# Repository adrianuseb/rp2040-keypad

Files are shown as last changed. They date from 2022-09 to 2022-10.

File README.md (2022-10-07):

# RP2040-keypad

## Table of Contents
* [General Info](#general-information)
* [Design](#design)
* [Ordering](#ordering)
* [Flashing Firmware](#flashing-firmware)
* [Case](#case)
* [Assembly](#assembly)

## General Information

This project was made as a learning experience on how to design a MCU-based PCB with minimum components.
It is a 2-key Keypad based on Raspberry RP2040 MCU. It doesn't have any button to enter bootmode, and no LED indicator. Simplicity was the main target.

## Design

This board was designed with KiCad. It is a 4 layer board with signal on the outer layer and power on the inner layer. It has serial wire pin-hole to debugging
and a USB-C header for connection to the host and power. The switches used for the key are mechanical switches and they are connected to GPIO6 and GPIO7. The other end
of the switch connected directly to ground. For programming the BOOT jumper pad must be shorted before connecting the USB.

## Ordering

Ordering and assembly can be done easily at JLCPCB. [Manufacturing_JLCPCB](./Manufacturing_JLCPCB) provide all the necessary files like Gerber, BOM, and components
placement for ordering the board.

## Flashing firmware

Flashing firmware with RP2040 IC is a very simple task. Just short the BOOT jumper while connecting the USB to PC. The board should appear as a mass storage device
on the host PC. Then just copy the [.uf2 file](./rp2040-keypad-1000hz.uf2) there and the board should reset itself. The firmware is written with z and x as the key.

## Case

There is also a simple [case](./case.obj) for 3D printing. The following components are also required for the case:
  - 4 M2 14mm
  - 4 M2 hex nuts

## Assembly

1. Place both of the switch from the top case. It should hold the switches well
2. Align the PCB with the switch. Now should be the right time to solder the switches to the PCB
3. Insert all the hex nuts to the bottom case
4. Place the bottom case aligned with the top case and press until the PCB sits on the bottom case
5. Screw all the M2 screws to secure the case

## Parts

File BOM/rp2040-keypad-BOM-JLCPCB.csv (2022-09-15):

Comment | Designator | Footprint | LCSC
22u | C1,C2 | Capacitor_SMD:C_0603_1608Metric | C59461
22p | C16,C17 | Capacitor_SMD:C_0402_1005Metric | C1555
100n | C3,C4,C6,C7,C8,C9,C10,C11,C12,C13,C15 | Capacitor_SMD:C_0402_1005Metric | C1525
1u | C5,C14 | Capacitor_SMD:C_0402_1005Metric | C52923
USB_C_Receptacle_USB2.0 | J1 | Connector_USB:USB_C_Receptacle_HRO_TYPE-C-31-M-12 | C165948
5k1 | R1,R2 | Resistor_SMD:R_0402_1005Metric | C25905
27R4 | R3,R4 | Resistor_SMD:R_0402_1005Metric | C31439
1k | R5,R6 | Resistor_SMD:R_0402_1005Metric | C11702
AMS1117-3.3 | U1 | Package_TO_SOT_SMD:SOT-223-3_TabPin2 | C6186
RP2040 | U2 | Package_DFN_QFN:QFN-56-1EP_7x7mm_P0.4mm_EP3.2x3.2mm | C2040
W25Q128JVS | U3 | Package_SO:SOIC-8_5.23x5.23mm_P1.27mm | C97521
12Mhz | Y1 | Crystal:Crystal_SMD_3225-4Pin_3.2x2.5mm | C9002

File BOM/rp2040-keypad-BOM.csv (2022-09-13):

Source: | C:\Users\AugmentedRobotics014\Documents\GIThub\rp2040-keypad\KiCad\rp2040-keypad.kicad_sch
Date: | 13/09/2022 17:31:18
Tool: | Eeschema (6.0.7)
Generator: | C:\Program Files\KiCad\6.0\bin\scripting\plugins/bom_csv_grouped_by_value_with_fp.py
Component Count: | 36
Ref | Qnty | Value | Cmp name | Footprint | Description | Vendor
C1, C2, | 2 | 22u | C | Capacitor_SMD:C_0603_1608Metric | Unpolarized capacitor
C3, C4, C6, C7, C8, C9, C10, C11, C12, C13, C15, | 11 | 100n | C | Capacitor_SMD:C_0402_1005Metric | Unpolarized capacitor
C5, C14, | 2 | 1u | C | Capacitor_SMD:C_0402_1005Metric | Unpolarized capacitor
C16, C17, | 2 | 22p | C | Capacitor_SMD:C_0402_1005Metric | Unpolarized capacitor
H1, H2, H3, H4, | 4 | MountingHole | MountingHole | MountingHole:MountingHole_2.2mm_M2_DIN965 | Mounting Hole without connection
J1, | 1 | USB_C_Receptacle_USB2.0 | USB_C_Receptacle_USB2.0 | Connector_USB:USB_C_Receptacle_HRO_TYPE-C-31-M-12 | USB 2.0-only Type-C Receptacle connector
J2, | 1 | Conn_01x04_Male | Conn_01x04_Male | Connector_Wire:SolderWire-0.1sqmm_1x04_P3.6mm_D0.4mm_OD1mm | Generic connector, single row, 01x04, script generated (kicad-library-utils/schlib/autogen/connector/)
JP1, | 1 | 0 | SolderJumper_2_Open | Jumper:SolderJumper-2_P1.3mm_Open_Pad1.0x1.5mm | Solder Jumper, 2-pole, open
R1, R2, | 2 | 5k1 | R | Resistor_SMD:R_0402_1005Metric | Resistor
R3, R4, | 2 | 27R4 | R | Resistor_SMD:R_0402_1005Metric | Resistor
R5, R6, | 2 | 1k | R | Resistor_SMD:R_0402_1005Metric | Resistor
SW1, SW2, | 2 | SW_Push | SW_Push | Switch_Keyboard_Cherry_MX:SW_Cherry_MX_PCB_1.00u | Push button switch, generic, two pins
U1, | 1 | AMS1117-3.3 | AMS1117-3.3 | Package_TO_SOT_SMD:SOT-223-3_TabPin2 | 1A Low Dropout regulator, positive, 3.3V fixed output, SOT-223
U2, | 1 | RP2040 | RP2040 | Package_DFN_QFN:QFN-56-1EP_7x7mm_P0.4mm_EP3.2x3.2mm | A microcontroller by Raspberry Pi
U3, | 1 | W25Q128JVS | W25Q128JVS | Package_SO:SOIC-8_5.23x5.23mm_P1.27mm | 128Mb Serial Flash Memory, Standard/Dual/Quad SPI, SOIC-8
Y1, | 1 | 12Mhz | Crystal_GND24 | Crystal:Crystal_SMD_3225-4Pin_3.2x2.5mm | Four pin crystal, GND on pins 2 and 4

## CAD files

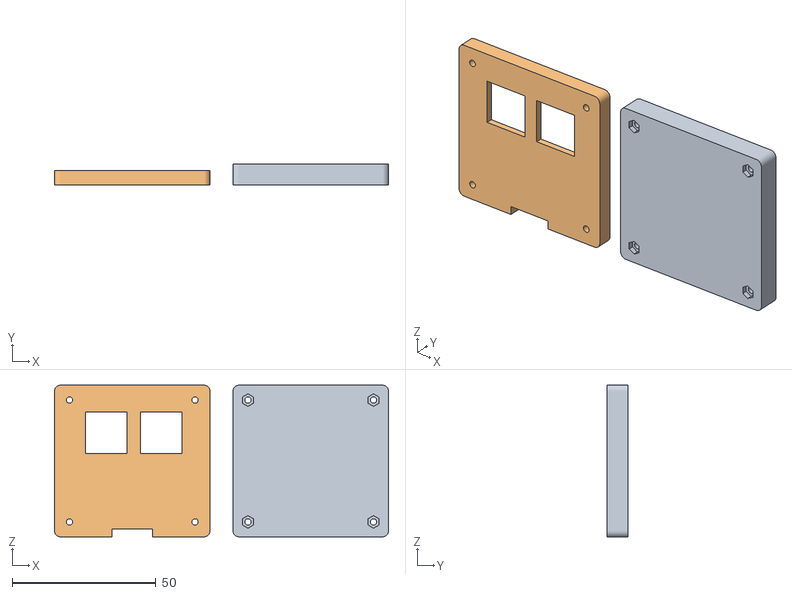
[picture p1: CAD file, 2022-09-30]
case.obj
116.2 x 7.19 x 52.8
Mesh1 Group1 Model
Mesh19 Group2 Model

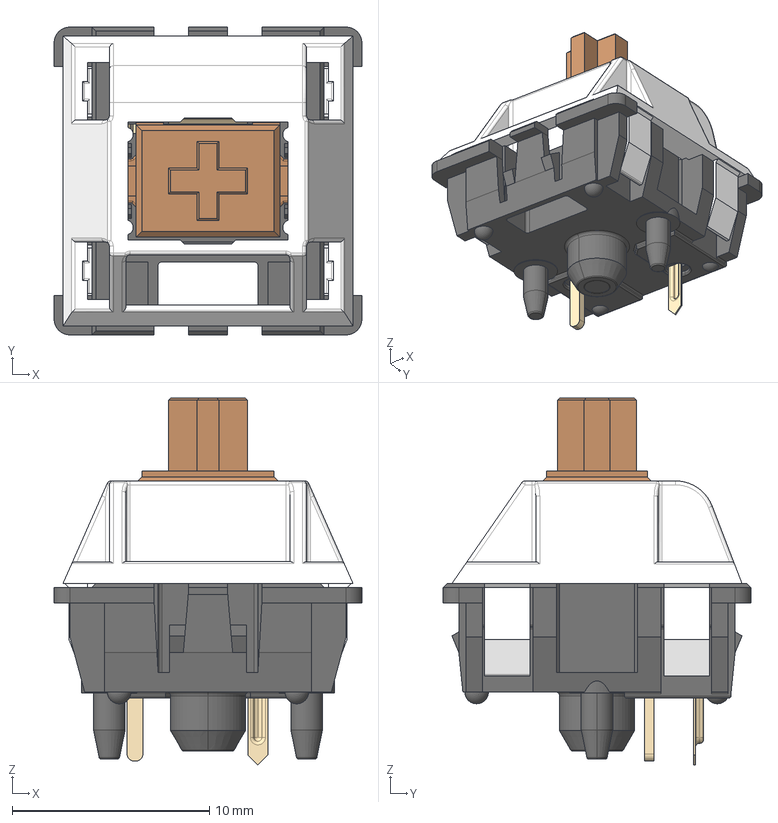
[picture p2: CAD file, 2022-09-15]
KiCad/Custom Library/3D Library/SW_Cherry_MX_PCB.stp
15.6 x 15.6 x 18.6 mm

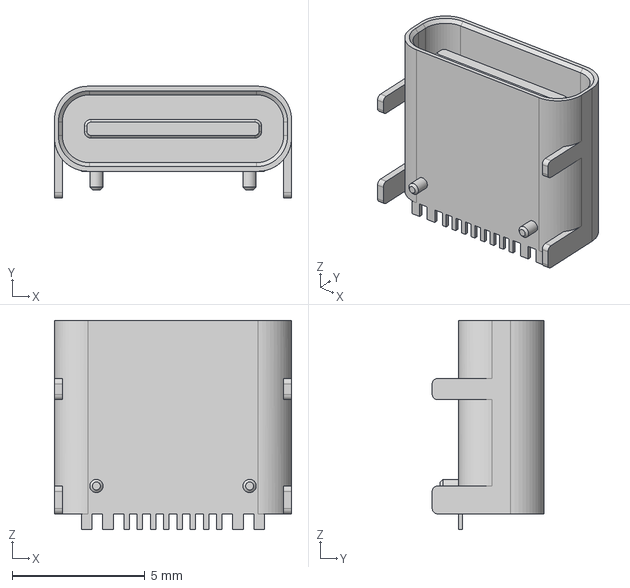
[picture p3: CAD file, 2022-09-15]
KiCad/Custom Library/3D Library/HRO TYPE-C-31-M-12.step
8.94 x 4.21 x 7.90 mm

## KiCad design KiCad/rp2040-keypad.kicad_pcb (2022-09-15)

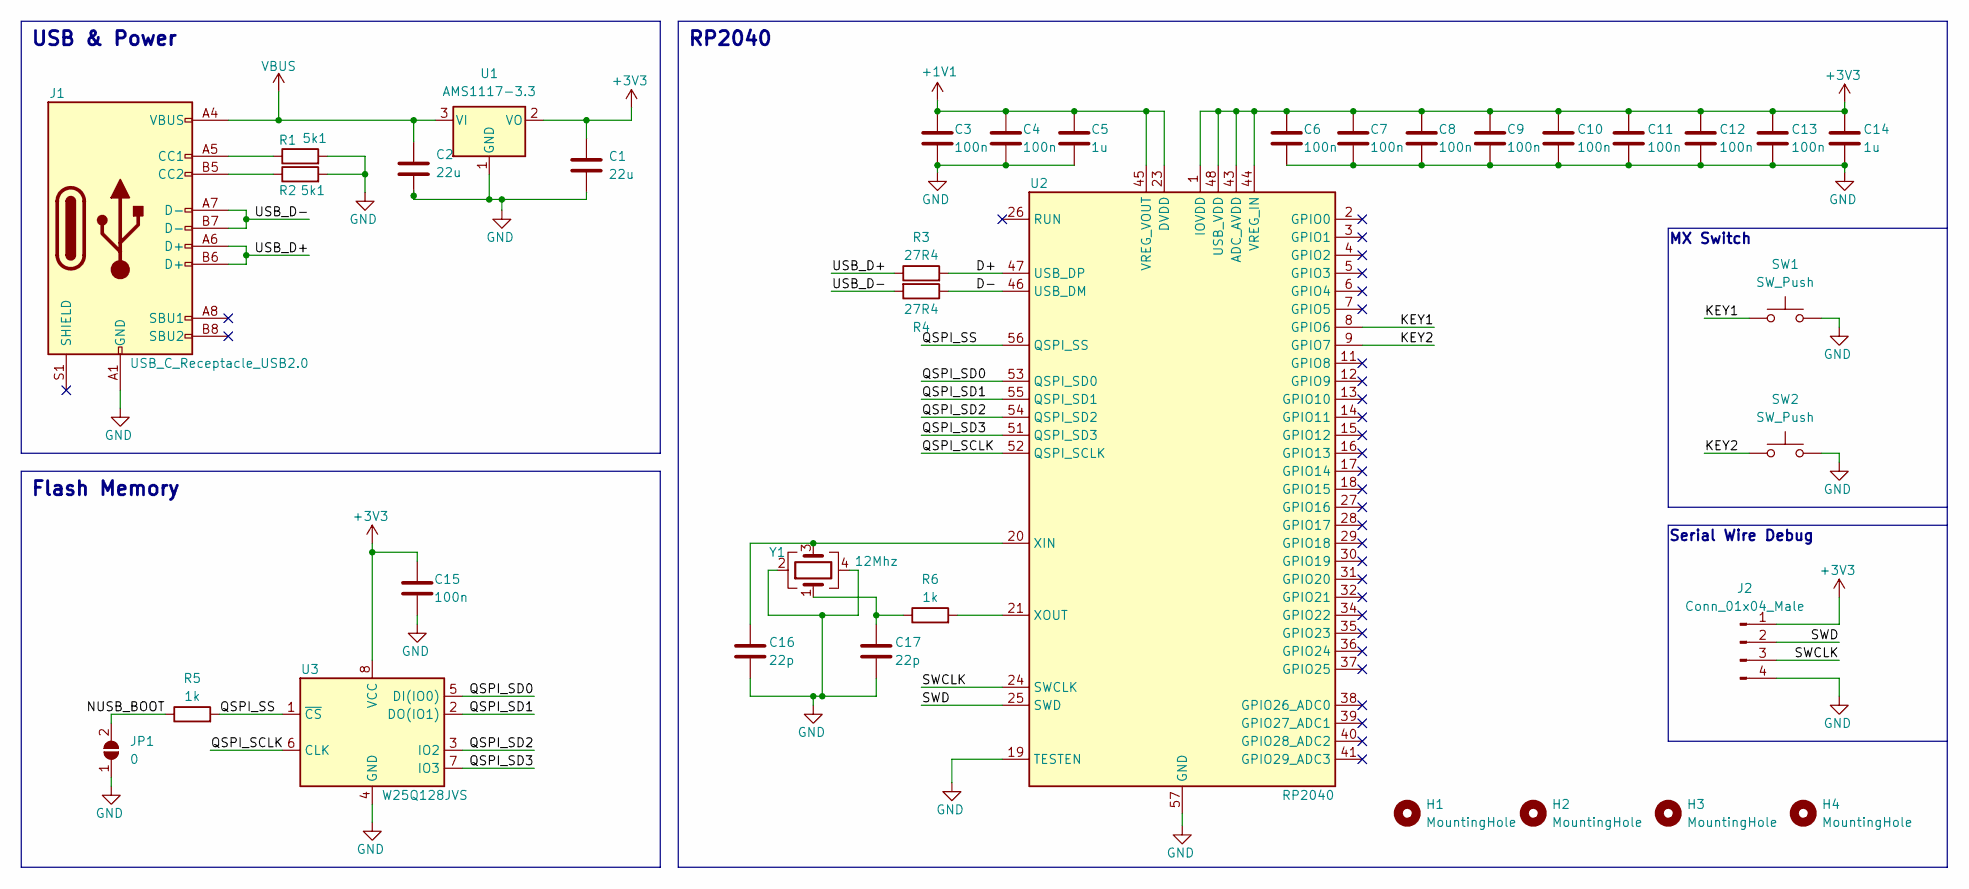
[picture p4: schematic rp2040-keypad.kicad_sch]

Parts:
C1, C2: 22u; C_0603_1608Metric; LCSC C59461
C3, C4, C6, C7, C8, C9, C10, C11, C12, C13, C15: 100n; C_0402_1005Metric; LCSC C1525
C5, C14: 1u; C_0402_1005Metric; LCSC C52923
C16, C17: 22p; C_0402_1005Metric; LCSC C1555
H1, H2, H3, H4: MountingHole; MountingHole_2.2mm_M2_DIN965
J1: USB_C_Receptacle_USB2.0; USB_C_Receptacle_HRO_TYPE-C-31-M-12; LCSC C165948
J2: Conn_01x04_Male; SolderWire-0.1sqmm_1x04_P3.6mm_D0.4mm_OD1mm
JP1: 0; SolderJumper-2_P1.3mm_Open_Pad1.0x1.5mm
R1, R2: 5k1; R_0402_1005Metric; LCSC C25905
R3, R4: 27R4; R_0402_1005Metric; LCSC C26971
R5, R6: 1k; R_0402_1005Metric; LCSC C11702
SW1, SW2: SW_Push; SW_Cherry_MX_PCB_1.00u
U1: AMS1117-3.3; SOT-223-3_TabPin2; LCSC C6186
U2: RP2040; QFN-56-1EP_7x7mm_P0.4mm_EP3.2x3.2mm; LCSC C2040
U3: W25Q128JVS; SOIC-8_5.23x5.23mm_P1.27mm; LCSC C97521
Y1: 12Mhz; Crystal_SMD_3225-4Pin_3.2x2.5mm; LCSC C9002

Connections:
+1V1: C3.1, C4.1, C5.1, U2.23 (DVDD), U2.45 (VREG_VOUT), U2.50 (DVDD)
+3V3: C1.1, C6.1, C7.1, C8.1, C9.1, C10.1, C11.1, C12.1, C13.1, C14.1, C15.1, J2.1, U1.2 (VO), U2.1 (IOVDD), U2.10 (IOVDD), U2.22 (IOVDD), U2.33 (IOVDD), U2.42 (IOVDD), U2.43 (ADC_AVDD), U2.44 (VREG_IN), U2.48 (USB_VDD), U2.49 (IOVDD), U3.8 (VCC)
/D+: R3.2, U2.47 (USB_DP)
/D-: R4.1, U2.46 (USB_DM)
/KEY1: SW1.1, U2.8 (GPIO6)
/KEY2: SW2.1, U2.9 (GPIO7)
/NUSB_BOOT: JP1.2 (B), R5.1
/QSPI_SCLK: U2.52 (QSPI_SCLK), U3.6 (CLK)
/QSPI_SD0: U2.53 (QSPI_SD0), U3.5 (DI(IO0))
/QSPI_SD1: U2.55 (QSPI_SD1), U3.2 (DO(IO1))
/QSPI_SD2: U2.54 (QSPI_SD2), U3.3 (IO2)
/QSPI_SD3: U2.51 (QSPI_SD3), U3.7 (IO3)
/QSPI_SS: R5.2, U2.56 (QSPI_SS), U3.1 (~CS)
/SWCLK: J2.3, U2.24 (SWCLK)
/SWD: J2.2, U2.25 (SWD)
/USB_D+: J1.A6 (D+), J1.B6 (D+), R3.1
/USB_D-: J1.A7 (D-), J1.B7 (D-), R4.2
GND: C1.2, C2.2, C3.2, C4.2, C5.2, C6.2, C7.2, C8.2, C9.2, C10.2, C11.2, C12.2, C13.2, C14.2, C15.2, C16.2, C17.2, J1.A1 (GND), J1.A12 (GND), J1.B1 (GND), J1.B12 (GND), J2.4, JP1.1 (A), R1.2, R2.2, SW1.2, SW2.2, U1.1 (GND), U2.19 (TESTEN), U2.57 (GND), U3.4 (GND), Y1.2, Y1.4
unnamed: C16.1, U2.20 (XIN), Y1.3
unnamed: C17.1, R6.1, Y1.1
unnamed: J1.A5 (CC1), R1.1
unnamed: J1.B5 (CC2), R2.1
unnamed: R6.2, U2.21 (XOUT)
VBUS: C2.1, J1.A4 (VBUS), J1.A9 (VBUS), J1.B4 (VBUS), J1.B9 (VBUS), U1.3 (VI)

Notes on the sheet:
MX Switch
Flash Memory
RP2040
Serial Wire Debug
USB & Power

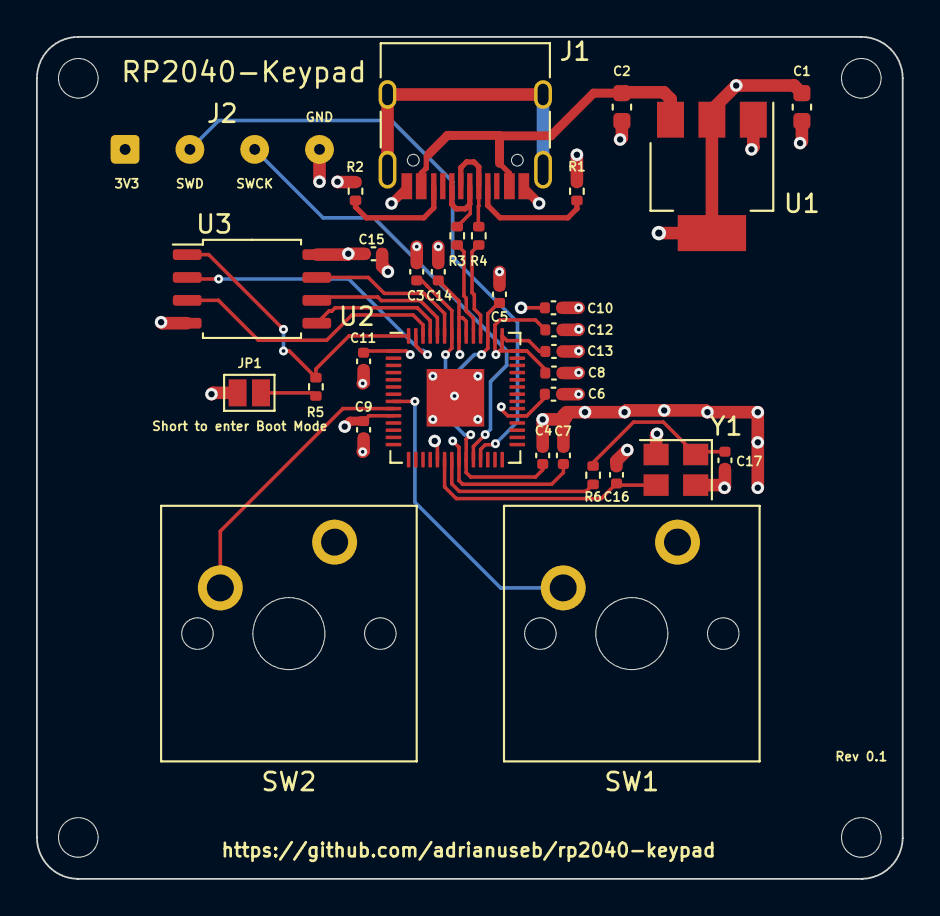
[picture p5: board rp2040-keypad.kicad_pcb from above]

Board: 4 copper layers, 48.1 x 46.8 mm, 36 parts (0 on the bottom side), 24 nets.

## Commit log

2022-09-11 Initial KiCad project
    [rp2040-keypad.kicad_pcb, rp2040-keypad.kicad_sch]
2022-09-13 Finish schematic and footprint assignment
    [rp2040-keypad.kicad_pcb, rp2040-keypad.kicad_sch]
2022-09-13 First draft completed ready to review
    [rp2040-keypad-BOM-JLCPCB.csv, rp2040-keypad-BOM.csv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]
2022-09-14 Rev 0.1 ready for production
    [rp2040-keypad-B_Cu.gbr, rp2040-keypad-B_Mask.gbr, rp2040-keypad-B_Paste.gbr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]
2022-09-15 Update silkscreen position and information
    [rp2040-keypad.kicad_pcb]
2022-09-15 Update gerber files
    [rp2040-keypad-B_Cu.gbr, rp2040-keypad-B_Mask.gbr, rp2040-keypad-B_Paste.gbr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]
2022-09-15 Added missing 3D Library
    [HRO TYPE-C-31-M-12.step, SW_Cherry_MX_PCB.stp, rp2040-keypad.kicad_pcb]
2022-09-15 Updated gerber files
    [rp2040-keypad-B_Cu.gbr, rp2040-keypad-B_Mask.gbr, rp2040-keypad-B_Paste.gbr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]
2022-09-15 Reposition and resize some ground vias
    [rp2040-keypad.kicad_pcb]
2022-09-15 Fix component ID R3&R4 for JLCPCB
    [rp2040-keypad-BOM-JLCPCB.csv, rp2040-keypad.kicad_sch]
2022-09-30 Add 3d case file
    [case.obj]

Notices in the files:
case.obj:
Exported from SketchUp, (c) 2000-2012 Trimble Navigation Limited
